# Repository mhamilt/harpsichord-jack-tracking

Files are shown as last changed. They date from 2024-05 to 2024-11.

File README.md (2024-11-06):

# Harpsichord Jack Tracking

This repository collects together all materials (CAD Drawings, diagrams, firmware source code) related to Harpsichord Jack Tracking Project at the NEMUS project.

|                              |
| :---------------------------------------------------------: |
| Side View of the model harpsichord used during development. |

- [Harpsichord Jack Tracking](#harpsichord-jack-tracking)
  - [Measurements](#measurements)
    - [Model Keyboard](#model-keyboard)
    - [Jack Pitch](#jack-pitch)
    - [Full Scale Keyboard](#full-scale-keyboard)
    - [Jack Pitch](#jack-pitch-1)
    - [Jack Travel](#jack-travel)
    - [PCB](#pcb)
      - [7 Sensor Face Board](#7-sensor-face-board)
    - [Gradient Tag](#gradient-tag)
    - [Diagram](#diagram)
  - [QRE1113 Notes](#qre1113-notes)
    - [Spacing](#spacing)
    - [Functionality](#functionality)
    - [Data sheets](#data-sheets)
    - [Multiplexing](#multiplexing)
      - [1. Using 2 Micro controllers](#1-using-2-micro-controllers)
  - [MIDI Specifications](#midi-specifications)
    - [Jack Differentiation](#jack-differentiation)
    - [Aftertouch](#aftertouch)

## Measurements

### Model Keyboard

###  Jack Pitch

| Jack | Centre distance from backboard (mm) |
| ---- | --- |
| 1 | `10.25` |
| 2 | `25.1` |
| 3 | `38.5` |

Gives a rough jack pitch of `14.4875 mm` with an offset of `10.25 mm`.

Pitch of the back row of jacks was determined by measuring from the open edge of the model to the front edge of the jack. Each jack had its width measured providing the values in the table below.

| Jack | Front edge dist (mm) | Width (mm) | Centre dist (mm) |
| ---- | --- | --- | --- |
| 4 | `59.85` | `4.25` | `61.975` |
| 5 | `45.25` | `4.30` | `47.400` |
| 6 | `31.20` | `4.60` | `33.500` |

Give a rough pitch of `14.2375 mm` with an offset of  `33.5 mm` from the front edge

### Full Scale Keyboard 

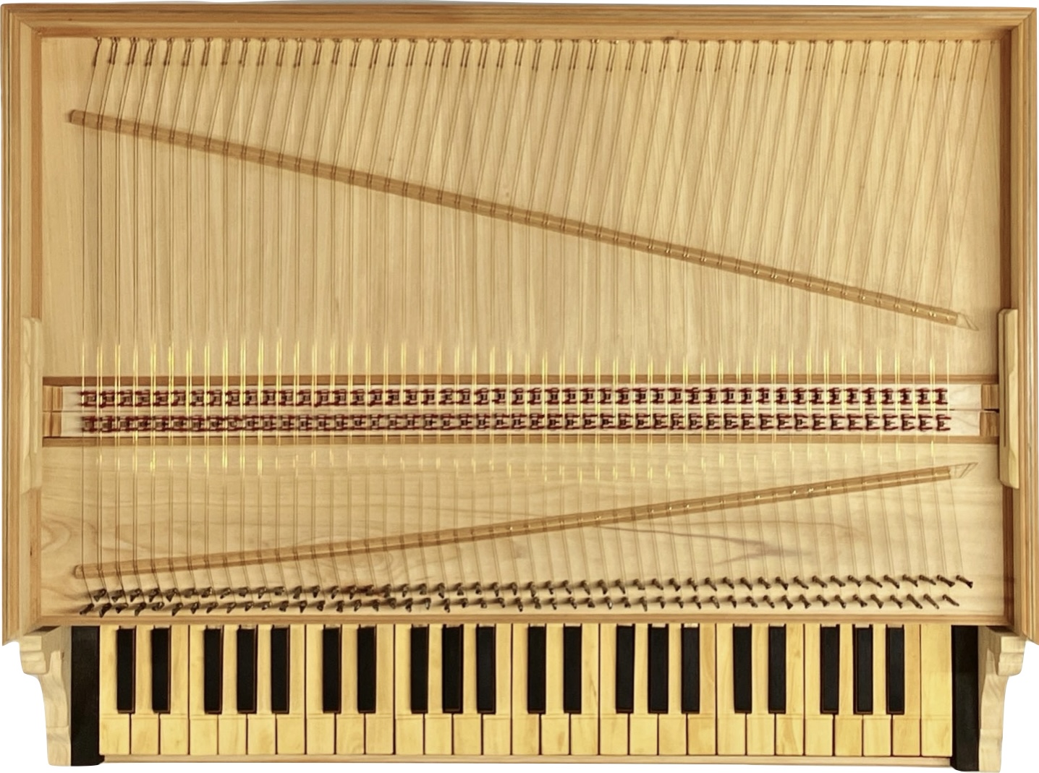
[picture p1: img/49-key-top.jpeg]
|        |
| :-----------------------------: |
| Top view of the 49-key keyboard |ll

The full scale version of the interface has 49 keys and 2 jack rows. The jacks are generally around `4.65 mm`.

###  Jack Pitch

There is not much variation in the pitch of the jacks. On average the centre-to-centre is `14.02 mm`. Likely error between jacks would compound across the full length. This should be compensated for by the separate pcbs which have groups of 7 sensors.

Space between the jacks is `9.75 mm`, meaning central pcbs will have to have less than half this distance (`4.875mm`) in order to slot together.

###  Jack Travel

The jacks have a height of `91.65mm`. Front jacks have a travel of about `8.5mm` and back jacks `9.0mm` between key release and full key press.

### PCB

With a pitch of `14.02 mm` a theoretical limit to the width of a 7-sensor PCB would be `98.2 mm`, but with margin required from traces this is not possible. The upper limit is `112.22 mm` but with variation during fabrication it is unwise to push the tolerance to the nearest `1/10 mm`. A `1.5 mm` tolerance brings the limit to about `99.7 mm` to `110.7 mm`

#### 7 Sensor Face Board

Face boards mount the QRE1113s perpendicular to the board so that there is no need to bend the through hole mounting legs during assembly.

There are a couple of designs, at at present what is most important is the hole mounts at (`18.00mm`, `10.00mm`) and (`18.00mm`, `81.40mm`)

### Gradient Tag

The QRE1113 reflects from a tag with a gradient printed.

The should be `40 mm` in length to avoid potential catching on the jack hole. The active area of the gradient need only be the length of the [jack travel](#jack-travel)

### Diagram

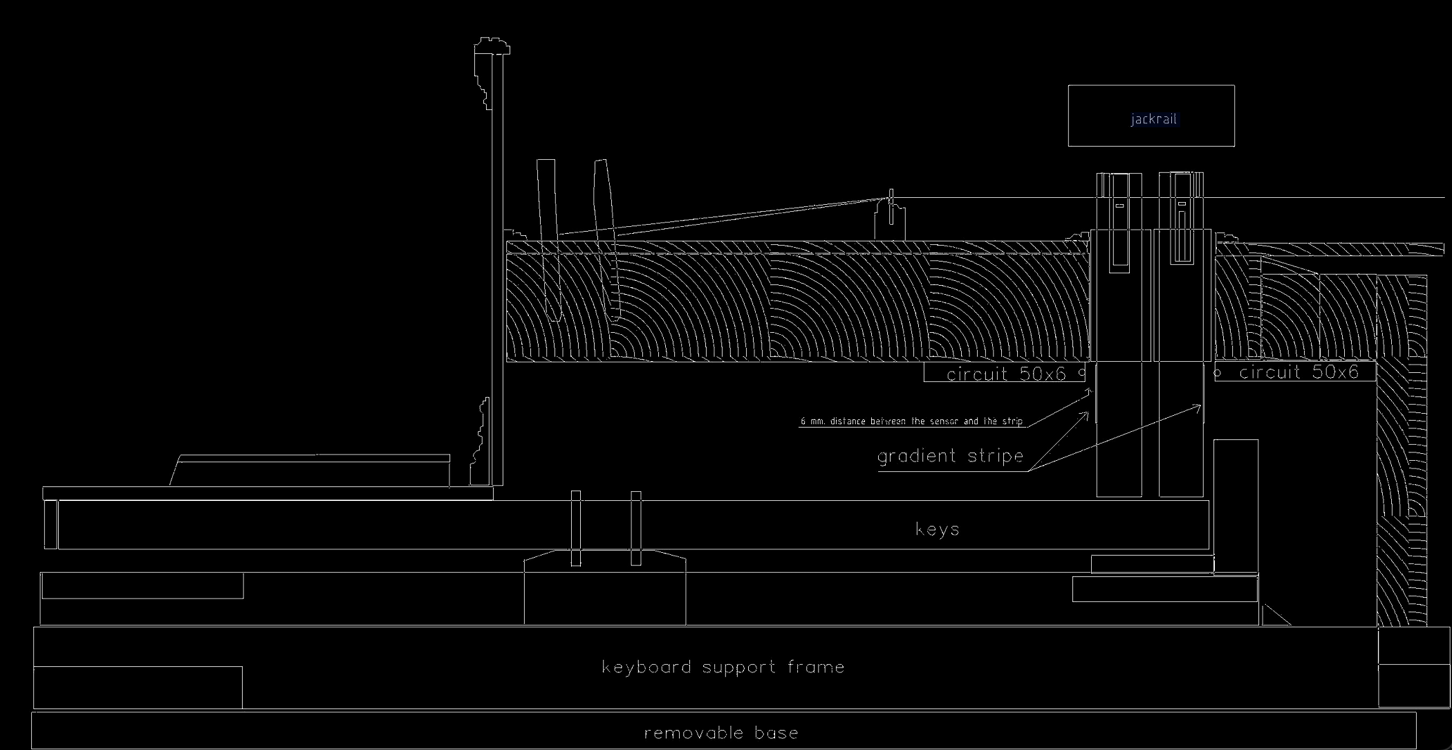
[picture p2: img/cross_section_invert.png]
|                 |
| :-----------------------------------------------: |
| Cross-section of full sized harpsichord interface |

## QRE1113 Notes

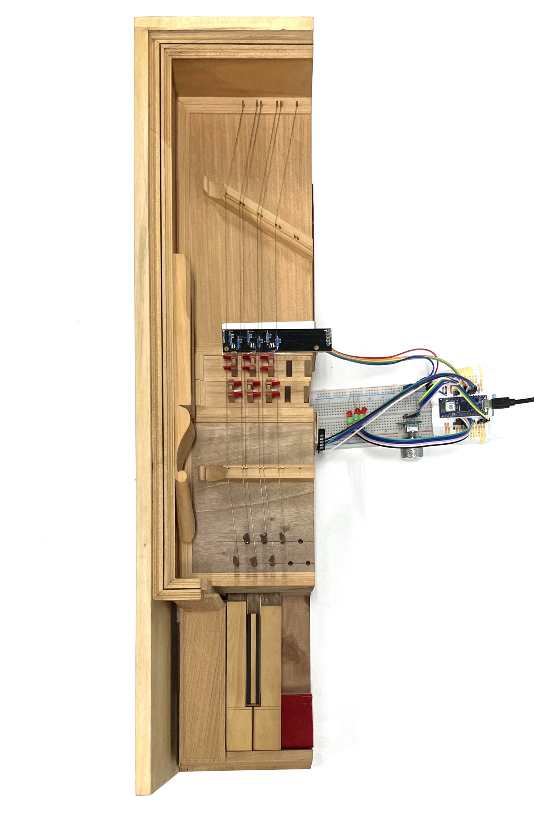
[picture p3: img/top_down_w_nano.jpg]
|              |
| :---------------------------------------------------------: |
| Model keyboard and QRE1113s attached to Arduino Nano 33 IoT |

Displacement of the jacks is measure using QRE1113 IR LED / Transistor pair. The section covers some general observations and helpful information about these sensors.

### Spacing

Distance between pins is `1.8mm` meaning the space from the centre is `0.9mm`. CAD placement should offset by `0.9mm` to compensate.

| | |
| --- | --- |
| short leg pitch | `1.80mm` |
| long leg pitch  | `3.80mm` |

### Functionality

QRE1113s are used with alongside adhesive strips with a black and white gradient printed on it, which are attached to each jack. 

The optimal distance between the strip and the sensor is around 6mm with a voltage reference of [`1.65V` provided by Arduino SAMD boards](https://www.arduino.cc/reference/en/language/functions/analog-io/analogreference/)

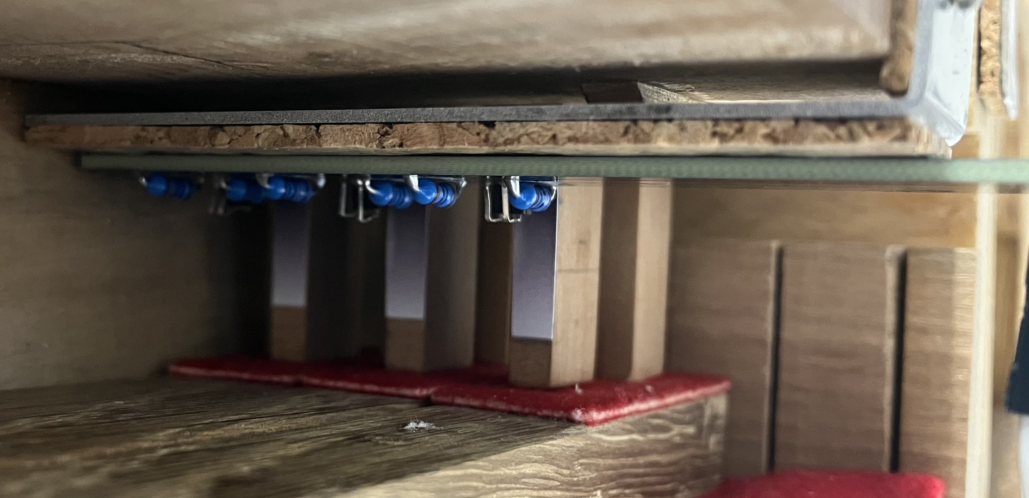
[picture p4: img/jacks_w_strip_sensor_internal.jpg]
|  |
| :-----------------------------------------: |
|     Jacks with gradient strip attached      |

### Data sheets

- [QRE1113 Datasheet](https://www.mouser.in/datasheet/2/308/QRE1113-1121523.pdf)

|  |  |
| :---: | :---: |
| QRE1113 Dimension. Not that pin 1 should always have a chamfer on the corner to help identify it. | QRE1113 Pinout |

### Multiplexing

- 14 Boards
- 7 sensors each
- 7 analog channels
- 8 channel multiplexer

- BLE Nano
  - 8 ADC channels A0 - A7
  - For 8 ADC channels an 8-channel multiplexer will allow for 8 boards to address 8 sensors.

Solutions:

1. Use 2 micro controllers, one for front, one for back
  - each a separate MIDI device
2. cascade front and back
  1. two groups of transistors
      - 16 transistors
        - 2 sets of 7 for signals
        - 2 extra for interfacing with the others
      - 2 extra digital pins used
  2. another bank of multiplexers
      - 7 multiplexers for groups of seven boards
      - 3 more digital pins for control 

#### 1. Using 2 Micro controllers

- Each sensor board needs 8 pins
  
  1. GND 
  2. VCC/VDD 5V
  3. VDD 3V
  4. Mux Address A
  5. Mux Address B
  6. Mux Address C
  7. LED Data
  8.  Signal 1
  9.  Signal 2
  10. Signal 3
  11. Signal 4
  12. Signal 5
  13. Signal 6
  14. Signal 7

## MIDI Specifications

Below are additional MIDI specifications retrieve the most information from the controller. 

Currently this is being written and subject to change

### Jack Differentiation

There is one channel per key as per [Standard MPE specifications](https://midi.org/mpe-midi-polyphonic-expression#:~:text=The%20MPE%20specification%20defines%20a,products%2C%20using%20MIDI%201.0%20messages.).

There are two note ons with associated velocities and note offs

A `note on` message `channel`, `pitch value`, `velocity`.

Velocity demarcates wether the note on message is related to the first jack or the second jack.

Given the signal obtained from the jack tracking does not provide the resolution in velocity to utilize the full 7 bit set of velocity values.

The First jack uses the velocity values from `0` to `63` and the second jack from `64` to `127`.

Note off messages use the same specification.

Therefore the physical model can relate the note off message to it's respective note on message.

example:

| | Jack1 | Jack2  |
| --- | ----- | --- |
| `channel`  | 1 | 1 |
| `pitch` | 56 | 56 |
| `velocity` | 0-63  | 64-127 |

**NOTE:** There is a secondary use case where the controller is used with a digital instrument that expects a standard MPE signal. In that case there _may_ be problem. However, it is not guaranteed to not work. Behavior in this case is undefined.

The same is true of the plug-in, which will be written to expect the above format of note messages.
As a result, the plug-in will need two modes of operation. A standard MPE for using with a standard MPE keyboard requiring a single note on/note off per key. The second mode designed specifically for the harpsichord keyboard interface. This gives control of the excitation of both of the strings.

### Aftertouch

Channel Pressure (MIDI Status event nybble `0xD`) is sent as one stream, taken from the front jack tracking signal.

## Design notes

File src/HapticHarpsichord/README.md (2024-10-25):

# Haptic Harpsichord Firmware

This documentation contain information for developing and deploying the firmware for the Haptic Harpsichord MIDI Controller

## Wiring

Pin layout adheres to the Arduino nano form factor
  
| Connection | Pin |
| --- | ----- |
| EEPROM SPI CLK  | D13 |
| EEPROM VCC | 3.3v  |
| AREF POT Switch | AREF  |
| PCB 0 QRE1113 | A0 |
| PCB 1 QRE1113 | A1 |
| PCB 2 QRE1113 | A2 |
| PCB 3 QRE1113 | A3 |
| PCB 4 QRE1113 | A4 |
| PCB 5 QRE1113 | A6 |
| PCB 6 QRE1113 | A7 |
| NC | 5v |
| NC | RESET |
| GND | GND |
| PSU `+` | VIN |

| Connection | Pin |
| --- | --- |
| Rotary CLK | D12 |
| Rotary DATA | D11 |
| Rotary Switch | D10 |
| LED Data | D9 |
| Mux C | D8 |
| Mux B | D7 |
| Mux A | D6 |
| Mux Interrupt | D5 |
| EEPROM SPI MISO | D4 |
| EEPROM SPI MOSI | D3 |
| EEPROM SPI CS | D2 |
| NC | RX / D1 |
| NC | TX / D0 |

## MIDI

## Power

The Arduino and the circuit are to be powered by 5V 5A PSU.

## Troubleshoooting

### Sensor Data Noise

If the sensors seem to return random noise and do not respond to an IR LED it is possible the interrupt for the multiplexers is not connected or is at a positive voltage. Ground the INT pin of the multiplexer.

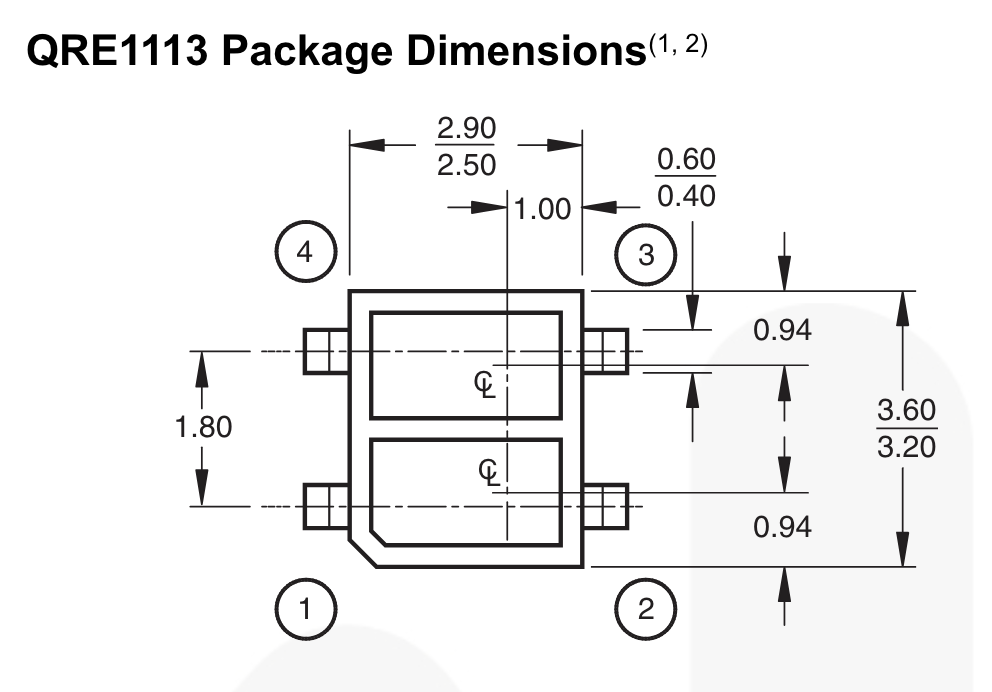
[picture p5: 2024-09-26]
img/qre1113-dims.png

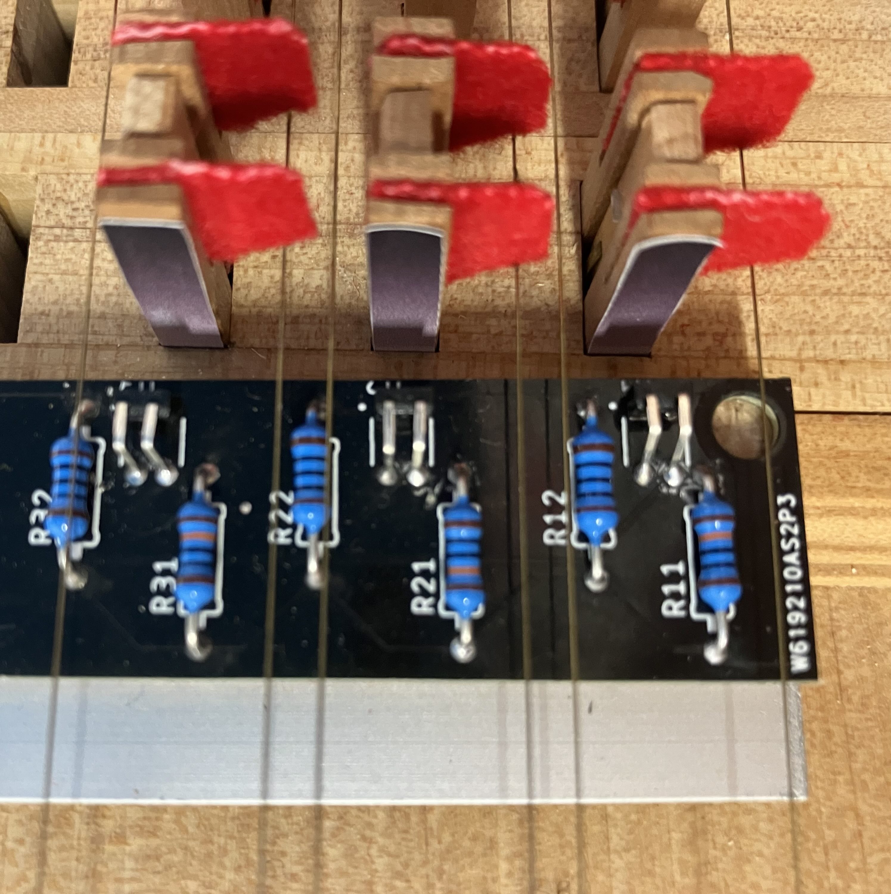
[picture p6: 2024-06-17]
img/jacks_w_strip_sensor.jpg

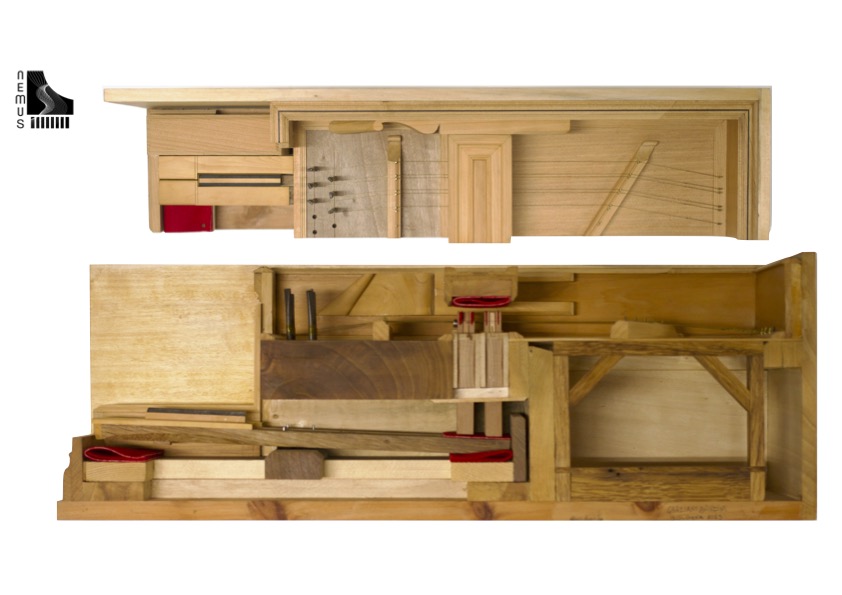
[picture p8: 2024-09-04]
img/haptic-harpsichord.jpg

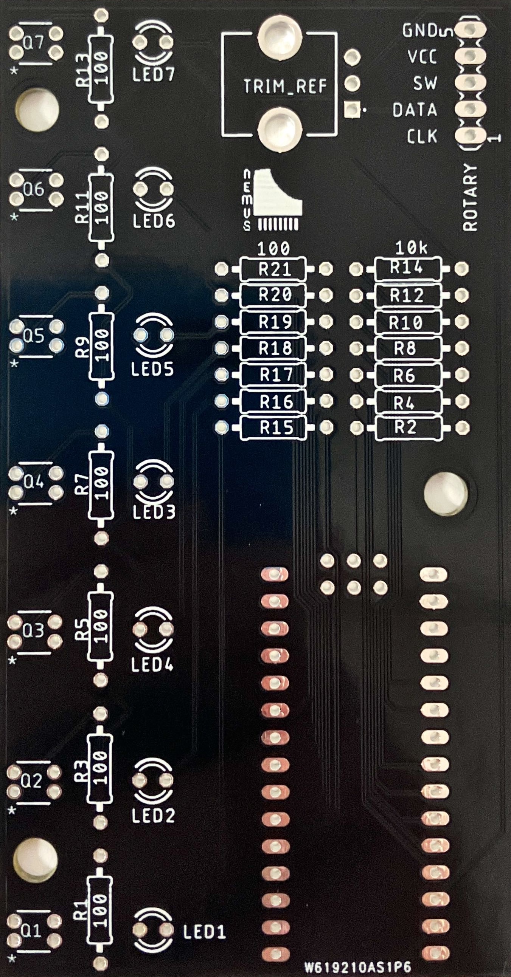
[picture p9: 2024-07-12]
img/7-jack-pcb.jpeg

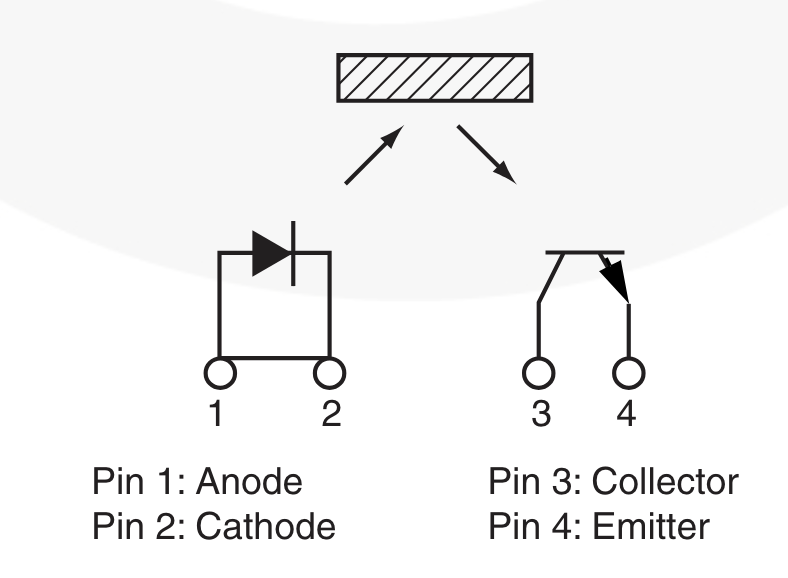
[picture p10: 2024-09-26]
img/qre1113-pins.png

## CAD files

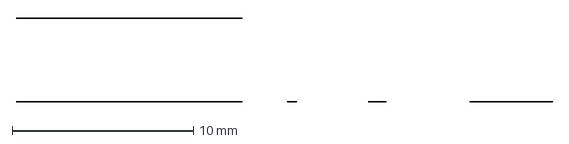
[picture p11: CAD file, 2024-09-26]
img/3-Key-Jack v18.dxf
29.6 x 4.60 mm

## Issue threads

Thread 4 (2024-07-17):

Tags sticking on full size model

mhamilt, 2024-07-17:
he gradient age length for the full size model (`20 mm` x `5 mm`) is too short and as a result the upper lip of the tag is getting caught during playing.

Probably easiest solved by extending the length of the tag. `40 mm` should do it

mhamilt, 2024-12-03:
Solved by cutting tag to full length of jack

Closed 2024-12-03.

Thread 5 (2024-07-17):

Redesign tag for full size model

mhamilt, 2024-07-17:
The distance of travel under the sensor is only around 9mm. The gradient could maybe do with a redesign to accommodate this, bearing in mind #4

Closed 2024-12-03.

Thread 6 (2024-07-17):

3D model for PCB supports

mhamilt, 2024-07-17:
A bracket is needed for adjusting PCB distance and making the installation more robust.

A fork bracket of some sort would allow for mounting a pub with sensors and pcb that are inline

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

28 units will be needed.

mhamilt, 2024-12-03:
Done

Models can be found in https://github.com/mhamilt/haptic-harpsichord-cad under the `stl/` directory for each PCB design.

3D printing and design in CAD is by far the best option so far.

Closed 2024-12-03.

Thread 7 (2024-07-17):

QRE1113 pcb redesign

mhamilt, 2024-07-17:
The QRE1113s used are those for through-hole mounting. At the moment, the design requires that the legs be bent but this is too costly in time and two risky as the legs easily break.

A new design is required where the QRE1113s can just be dropped in. This would mean that the PCB would sit at a 90º angle to the bracket #6. An additional L bracket would be needed

mhamilt, 2024-12-03:
Designs in https://github.com/mhamilt/haptic-harpsichord-cad

Closed 2024-12-03.

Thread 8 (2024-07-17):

QRE1113 Range Drop

mhamilt, 2024-07-17:
## The problem

There seems to be a drop in the full range of values from each sensor.

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

It roughly correlates with the distance each sensor is from the 3.3v source pin.

The closer each output is to `0` the lower the voltage.

I don't think this is a current problem. The board is use is an Arduino Nano 33 BLE, which has a max current for the 3.3v as `950 mA` [according to the datasheet](https://docs.arduino.cc/resources/datasheets/ABX00030-datasheet.pdf#page=6).

From the [QRE1113 datasheet](https://www.mouser.in/datasheet/2/308/QRE1113-1121523.pdf#page=4), each sensor is maximally rated to `70 mA`, `20 mA` for the sensor transistor collector and `50 mA` for the emitter. a `100 ohm` resistor has been used in front of the VCC pin for each QRE1113. This means max `33 mA` should be going to each QRE1113 unit, around `230 mA` total for 7 sensors.

The problem shouldn't be under current, but there is possibly a flaw in the approach to the layout of the trace on the PCB

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

| 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 |
| -------------------------------------------------------------- |
| Note the 3.3V line from the penultimate pin on the bottom left from each sensor taps into |

It may also be just variation within the sensors. More testing required.

## Solutions

Should be ablate adjust in software, the ranges available are still more than enough for MIDI purposes.

It may be worth while adding in a trim pot for each sensor to help adjust, but applying that to 98 sensor seems quite drastic.

This may also be addressed by simply powering the sensors as and when they are needed.

mhamilt, 2024-12-03:
Most likely this was done to sensor tag placement. After implementing on the full model, all sensors _could_ be made to give  similar reading so long as the gradient of the sensor surface was placed.

Variations in

- jack height
- leather thickness
- tag placement
- key thickness
- key displacement

mean that there will always be some variation, but data should be useable.

Closed 2024-12-03.

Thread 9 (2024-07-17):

Power Electronics

mhamilt, 2024-07-17:
At some point this device is actually going to need to be powered somehow.

If the current design is expanded to all 98 jacks, the power draw would be around 4A.

Need to find a suitable voltage regulator / converter for both the microcontroller and all sensors

mhamilt, 2024-12-03:
After testing, 49 sensors draw around 1 Amp at 5V.

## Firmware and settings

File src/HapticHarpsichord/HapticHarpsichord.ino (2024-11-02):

/*
  Haptic Harposchord

  This is the full firmware for the haptic harpsochord using the arduino IDE development platform

  At time of writing the microcontroller for the project is not fixed. As such there may be macros to help make the correct changes to firmware behaviour.

  | Connection      | Pin   |
  | --------------- | ----- |
  | NC              | D13   |
  | EEPROM VCC      | 3.3v  |
  | AREF POT Switch | AREF  |
  | PCB 0 QRE1113   | A0    |
  | PCB 1 QRE1113   | A1    |
  | PCB 2 QRE1113   | A2    |
  | PCB 3 QRE1113   | A3    |
  | PCB 4 QRE1113   | A4    |
  | PCB 5 QRE1113   | A6    |
  | PCB 6 QRE1113   | A7    |
  | NC              | 5v    |
  | NC              | RESET |
  | GND             | GND   |
  | PSU `+`         | VIN   |

  | Connection      | Pin     |
  | --------------- | ------- |
  | Rotary CLK      | D12     |
  | Rotary DATA     | D11     |
  | Rotary Switch   | D10     |
  | LED Data        | D9      |
  | Mux C           | D8      |
  | Mux B           | D7      |
  | Mux A           | D6      |
  | EEPROM SPI CLK  | D5      |
  | EEPROM SPI MISO | D4      |
  | EEPROM SPI MOSI | D3      |
  | EEPROM SPI CS   | D2      |
  | NC              | RX / D1 |
  | NC              | TX / D0 |


 */
//-----------------------------------------------------------------------------
// Board specific libraries
#ifdef ARDUINO_ARDUINO_NANO33BLE
#include <PluggableUSBMIDI.h>
#elif ESP32
#include <Arduino.h>
#include <Adafruit_TinyUSB.h>  // verision 3.1.3
#include <MIDI.h>
#elif ARDUINO_ARCH_STM32
#endif
//-----------------------------------------------------------------------------
// Board Agnostics Libraries
#include <Rotary.h>
#include <Button2.h>
#include <Adafruit_NeoPixel.h>
#include <Adafruit_FRAM_SPI.h>
#include <SPI.h>
//-----------------------------------------------------------------------------
// Local Headers
#include "error_codes.h"
//-----------------------------------------------------------------------------
#define ALWAYS_DEBUG true
//-----------------------------------------------------------------------------
// Enums
enum JackState {
  PLUCKED,
  PLUCK,
  PRESSING,
  RELEASING,
  RELEASED,
  UNKNOWN_KEY_STATE
};
//-----------------------------------------------------------------------------
#define numSensors 49
#define numMuxChannels 7
#define numPcbs 7

#if (numMuxChannels * numPcbs != numSensors)
#error "Check product of mux channels and number of PCBs is equal to total number of sensors"
#endif
//-----------------------------------------------------------------------------
constexpr byte key2index(byte k);
byte index2note(byte index, byte transpose = 0);
void rotate(Rotary& r);
//-----------------------------------------------------------------------------
// Config Variables
const unsigned long midiBaudRate = 115200;  // 31250;
bool executeDebugMode = false;
//-----------------------------------------------------------------------------
// Operation Mode Variables
bool isKeySelectMode = true;
uint8_t curKeyIndex = key2index(25);
//-----------------------------------------------------------------------------
// Multiplexer Variables
const size_t muxPinA = 6;
const size_t muxPinB = 7;
const size_t muxPinC = 8;
// const size_t muxPinD = 9;
//-----------------------------------------------------------------------------
// Sensor variables
uint16_t sensorReadingsA[numSensors];
uint16_t sensorReadingsB[numSensors];
// uint16_t lastSensorReading[numSensors];
uint16_t* tempPointer;
uint16_t sensorAvgMaxima[numSensors];
uint16_t sensorAvgMinima[numSensors];
uint16_t pluckThresholds[numSensors];
uint16_t releaseThresholds[numSensors];
uint32_t readCount = 0;
uint64_t lastRead = 0;
constexpr byte avgSize = 4;
uint16_t sensorWindowReadings[numSensors][avgSize];
byte windex = 0;
uint16_t* prevSensorReadings = sensorReadingsB;
uint16_t* currSensorReadings = sensorReadingsA;
//-----------------------------------------------------------------------------
// Jack States
JackState jackStatesA[numSensors];
JackState jackStatesB[numSensors];
JackState* jackStates = jackStatesA;
JackState* prevStates = jackStatesB;
JackState* tempStatePointer;
//-----------------------------------------------------------------------------
// LED Variables
const size_t ledPin = 9;
Adafruit_NeoPixel leds(numSensors, ledPin, NEO_GRB + NEO_KHZ800);
unsigned long now = 0;
static int step = 0;

//-----------------------------------------------------------------------------
// Rotary Variables
const byte ROTARY_PINC = 12;
const byte ROTARY_PINA = 10;
const byte ROTARY_PINB = 11;
const byte CLICKS_PER_STEP = 4;
const byte MIN_POS = 0;
const uint16_t MAX_POS = numSensors - 1;
const byte START_POS = 0;
const byte INCREMENT = 1;
Rotary rotary = Rotary(ROTARY_PINA, ROTARY_PINB, CLICKS_PER_STEP, MIN_POS, MAX_POS, START_POS, INCREMENT);
Button2 button = Button2(ROTARY_PINC);
//-----------------------------------------------------------------------------
// EEPROM Variables
const uint8_t FRAM_CS = 2;
const uint8_t FRAM_MOSI = 3;
const uint8_t FRAM_MISO = 4;
const uint8_t FRAM_SCK = 5;
Adafruit_FRAM_SPI fram = Adafruit_FRAM_SPI(FRAM_SCK, FRAM_MISO, FRAM_MOSI, FRAM_CS);
const uint8_t addrSizeInBytes = 2;  // Default to address size of two bytes
const uint16_t tagAddress = 0;
const uint8_t thresholdTag[4] = { 'D', 'A', 'T', 'A' };
// const uint8_t maxTag[4] = { 'M', 'A', 'X', 'I' };
// const uint8_t minTag[4] = { 'M', 'I', 'N', 'I' };
const uint16_t pluckValAddress = tagAddress + 4;
//-----------------------------------------------------------------------------
// MIDI Variables
USBMIDI MidiUSB;

void setup() {
  Serial.begin(midiBaudRate);
  // Save some power
  digitalWrite(PIN_ENABLE_I2C_PULLUP, LOW);
  digitalWrite(PIN_ENABLE_SENSORS_3V3, LOW);
  // digitalWrite(LED_PWR, LOW);
  /// setup mux
  pinMode(muxPinA, OUTPUT);
  pinMode(muxPinB, OUTPUT);
  pinMode(muxPinC, OUTPUT);

  /// init LEDs
  pinMode(LEDR, OUTPUT);
  pinMode(LEDG, OUTPUT);
  pinMode(LEDB, OUTPUT);

  digitalWrite(LEDR, HIGH);
  digitalWrite(LEDG, HIGH);
  digitalWrite(LEDB, HIGH);

  for (int i = 0; i < numSensors; i++) {
    sensorAvgMinima[i] = 1024;
    pluckThresholds[i] = 500;
  }

  leds.begin();
  leds.clear();
  
  /// setup EEPROM
  if (!fram.begin())
    halt(FRAM_NOT_FOUND);

  readPluckFromEEPROM();

  // calibrarte sensors
  calibrate();

  if (button.isPressed() or ALWAYS_DEBUG) {
    debugLoop();
  }
}

void loop() {

  // readSensors();
  // rotary.loop();
  // button.loop();

  // for (int i = 0; i < numSensors; i++) {
  //   if (currSensorReadings[i] < pluckThresholds[i] and prevSensorReadings[i] > pluckThresholds[i]) {
  //     noteOff(0, index2note(i), 100);
  //   } else if (currSensorReadings[i] > pluckThresholds[i] and prevSensorReadings[i] < pluckThresholds[i]) {
  //     noteOn(0, index2note(i), 100);
  //   }
  // }

  // readCount++;

  // if (readCount > 2048) {
  //   readCount = 0;
  //   Serial.println(millis() - lastRead);
  //   lastRead = millis();
  // }

    if (millis() - now > 16) {
      // rainbow(step++);
      breath(step++);
      now = millis();
    }
    // rotary.loop();
  
}

void calibrate() {
  static const int numReading = 8;

  for (int i = 0; i < numSensors; i++) {
    unsigned long runningTotal = 0;

    for (int k = 0; k < numReading; k++) {
      runningTotal += readSensor(i);
    }
    sensorAvgMaxima[i] = runningTotal /= numReading;
  }
}

constexpr byte index2key(byte i) {
  return (numSensors - i);
}

constexpr byte key2index(byte k) {
  if (k > numSensors)
    k = numSensors;
  else if (k < 1)
    k = 1;
  return (numSensors - k);
}

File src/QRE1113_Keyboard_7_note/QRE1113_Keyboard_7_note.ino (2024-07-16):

/*
  QRE1113  6-Note Keyboard
  
  Firmware for 3-key, 6-jack Harpsochord model


  Wiring:
  
    |   Connection   | Pin |
    | -------------- | --- |
    | Jack 0 QRE1113 | A0  |
    | Jack 1 QRE1113 | A1  |
    | Jack 2 QRE1113 | A2  |
    | Jack 3 QRE1113 | A3  |
    | Jack 4 QRE1113 | A4  |
    | Jack 5 QRE1113 | A6  |
    | Jack 6 QRE1113 | A7  |
    | Jack 0 LED     | D9  |
    | Jack 1 LED     | D8  |
    | Jack 2 LED     | D7  |
    | Jack 3 LED     | D6  |
    | Jack 4 LED     | D5  |
    | Jack 5 LED     | D4  |
    | Jack 6 LED     | D3  |
    | Rotary CLK     | D12 |
    | Rotary DATA    | D11 |
    | Rotary Switch  | D10 |

  Jack Layout:

    ┌─┐┌─┐┌─┐
    ┤3│┤4│┤5│
    └─┘└─┘└─┘
    ┌─┐┌─┐┌─┐
    │0├│1├│2├
    └─┘└─┘└─┘

    ┌──┬─┬──┐
    │  │ │  │
    │  │ │  │
    │  │ │  │
    │  └┬┘  │
    │   │   │
    │   │   │
    └───┴───┘
*/
//-----------------------------------------------------------------------------
#include <MIDIUSB.h>
#include <Rotary.h>
#include <Button2.h>
#include <FlashStorage_SAMD.h>
//-----------------------------------------------------------------------------

enum JackState {
  PLUCKED,
  PLUCK,
  PRESSING,
  RELEASING,
  RELEASED,
  UNKNOWN_KEY_STATE
};

//-----------------------------------------------------------------------------
// Sensor variables
const byte numSensors = 6;
unsigned long sensorAverages[numSensors];
unsigned long sensorHomeValues[numSensors];
const pin_size_t sensorPins[numSensors] = { A0, A1, A2, A3, A6, A7 };
const byte ledPins[numSensors] = { 3, 5, 7, 2, 4, 6 };
const bool ledFeedback = true;
int sensorValues[numSensors] = { 0, 0, 0, 0, 0, 0 };
int prevValues[numSensors] = { 0, 0, 0, 0, 0, 0 };
byte noteMap[numSensors] = { 70, 71, 72, 70, 71, 72 };
byte pluckValues[numSensors] = { 65, 80, 180, 80, 77, 36 };
byte releaseValues[numSensors] = { 24, 24, 24, 24, 24, 24 };
JackState jackStates[numSensors] = { RELEASED, RELEASED, RELEASED, RELEASED, RELEASED, RELEASED };
JackState prevStates[numSensors] = { RELEASED, RELEASED, RELEASED, RELEASED, RELEASED, RELEASED };
//-----------------------------------------------------------------------------
// Rotary Variables
const byte BUTTON_PIN = 10;
const byte ROTARY_PIN1 = 11;
const byte ROTARY_PIN2 = 12;
const byte CLICKS_PER_STEP = 4;
const byte MIN_POS = 0;
const byte MAX_POS = numSensors - 1;
const byte START_POS = 0;
const byte INCREMENT = 1;
Rotary r = Rotary(ROTARY_PIN1, ROTARY_PIN2, CLICKS_PER_STEP, MIN_POS, MAX_POS, START_POS, INCREMENT);
Button2 b = Button2(BUTTON_PIN);
byte curKey = 0;
bool isKeySelectMode = true;
bool executeDebugMode = false;
//-----------------------------------------------------------------------------
// EEPROM Vars
const uint16_t tagAddress = 0;
const char tagName[4] = { 'D', 'A', 'T', 'A' };
const uint16_t pluckValAddress = tagAddress + 4;
//-----------------------------------------------------------------------------

void setup() {
  analogReference(AR_INTERNAL1V65);
  Serial.begin(9600);
  calibrate();
  readPluckFromEEPROM();
  for (auto pin : ledPins) {
    pinMode(pin, OUTPUT);
  }
  delay(200);  // give some padding to allow button to be pressed

  if (b.isPressed()) {

    setupDebugMode();

    while (executeDebugMode)
      debugModeLoop();

    exitDebug();
  }
}

void loop() {
  updateSensorReadings();
  updateJackStates();
  // printReadings();
  checkJackStates();
  printJackStates();
  delay(1);
}

//-----------------------------------------------------------------------------

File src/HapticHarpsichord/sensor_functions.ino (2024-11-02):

/// Read all sensors and put results in currSensorReadings
void readSensors() {

  for (int mux = 0; mux < numMuxChannels; mux++) {

    // switch mux channel
    digitalWrite(muxPinA, (mux >> 0) & 0x1);
    digitalWrite(muxPinB, (mux >> 1) & 0x1);
    digitalWrite(muxPinC, (mux >> 2) & 0x1);
    // digitalWrite(muxPinD, (mux >> 3) & 0x1);

    for (int adc = 0; adc < numPcbs; adc++) {

      int i = mux + (adc * numPcbs);

      sensorWindowReadings[i][windex] = analogRead(A0 + adc);

      uint16_t total = 0;

      for (int avg = 0; avg < avgSize; avg++) {
        total += sensorWindowReadings[i][avg];
      }

      currSensorReadings[i] = total / avgSize;
      // currSensorReadings[i] = analogRead(A0 + adc);
    }
  }
  
  windex++;
  if (windex >= avgSize) {
    windex = 0;
  }

  // pointer swap
  tempPointer = prevSensorReadings;
  prevSensorReadings = currSensorReadings;
  currSensorReadings = tempPointer;
}

//-----------------------------------------------------------------------------
/// Read a single sensor and return its raw value
unsigned int readSensor(byte index) {
  int adc = index / numPcbs;
  int mux = index - adc * numPcbs;

  digitalWrite(muxPinA, (mux >> 0) & 0x1);
  digitalWrite(muxPinB, (mux >> 1) & 0x1);
  digitalWrite(muxPinC, (mux >> 2) & 0x1);
  // digitalWrite(muxPinD, (mux >> 3) & 0x1);

  return analogRead(A0 + adc);
}


//-----------------------------------------------------------------------------
void calibrateSensors() {
  setThresholdsFromEEPROM();
  readSensors();
  setAverages();
}

//-----------------------------------------------------------------------------

void setThresholdsFromEEPROM() {
}

//-----------------------------------------------------------------------------

void setAverages() {
}

//-----------------------------------------------------------------------------

byte getOnVelocity(int j) {

  byte velocity;
  if (j < 3) {

    velocity = map(currSensorReadings[j] - prevSensorReadings[j], 1, 180, 1, 63);
    if (velocity < 1)
      velocity = 1;
    else if (velocity > 63)
      velocity = 63;

  } else {
    {
      velocity = map(currSensorReadings[j] - prevSensorReadings[j], 1, 180, 65, 127);
      if (velocity < 65)
        velocity = 65;
      else if (velocity > 127)
        velocity = 127;
    }
  }
}

//-----------------------------------------------------------------------------

byte getOffVelocity(int j) {
  byte velocity;
  if (j < 3) {

    velocity = map(currSensorReadings[j] - prevSensorReadings[j], 1, 180, 1, 63);
    if (velocity < 1)
      velocity = 1;
    else if (velocity > 63)
      velocity = 63;

  } else {
    {
      velocity = map(currSensorReadings[j] - prevSensorReadings[j], 1, 180, 65, 127);
      if (velocity < 65)
        velocity = 65;
      else if (velocity > 127)
        velocity = 127;
    }
  }
}

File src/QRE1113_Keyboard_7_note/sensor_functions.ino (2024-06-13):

//-----------------------------------------------------------------------------

void calibrate() {
  Serial.print("Calibrating.... ");

  for (int j = 0; j < 8; j++)
    for (int i = 0; i < numSensors; i++)
      sensorHomeValues[i] += analogRead(sensorPins[i]);

  for (int i = 0; i < numSensors; i++)
    sensorHomeValues[i] >>= 3;

  Serial.print("Done!");
}

//-----------------------------------------------------------------------------

void updateSensorReadings() {
  for (int i = 0; i < numSensors; i++) {
    prevValues[i] = sensorValues[i];
    sensorValues[i] = map(analogRead(sensorPins[i]), sensorHomeValues[i], 130, 0, 255);
    sensorValues[i] = (sensorValues[i] < 0) ? 0 : sensorValues[i];
  }
}

//-----------------------------------------------------------------------------

void updateJackStates() {

  for (int i = 0; i < numSensors; i++) {
    prevStates[i] = jackStates[i];
    if (prevValues[i] <= releaseValues[i]) {
      jackStates[i] = RELEASED;
    } else if (prevValues[i] < pluckValues[i] and sensorValues[i] > pluckValues[i]) {
      jackStates[i] = PLUCK;
    } else if (prevValues[i] > pluckValues[i] and sensorValues[i] > pluckValues[i]) {
      jackStates[i] = PLUCKED;
    }
  }
}

//-----------------------------------------------------------------------------

void checkJackStates() {
  bool anyTrigger = false;

  for (int i = 0; i < numSensors; i++) {
    if (jackStates[i] == PLUCK and prevStates[i] == RELEASED) {
      byte velocity = getVelocity(i);
      Serial.print("velocity: ");
      Serial.println(velocity);
      noteOn(0, noteMap[i], velocity);
      if (ledFeedback) {
        digitalWrite(ledPins[i], HIGH);
      }

    } else if (jackStates[i] == RELEASED and prevStates[i] != RELEASED) {
      byte velocity = prevValues[i] - sensorValues[i];
      noteOff(0, noteMap[i], velocity);
      if (ledFeedback) {
        digitalWrite(ledPins[i], LOW);
      }
    }
  }
}


byte getOnVelocity(int j) {
  byte velocity;
  if (j < 3) {

    velocity = map(sensorValues[j] - prevValues[j], 1, 180, 1, 63);
    if (velocity < 1)
      velocity = 1;
    else if (velocity > 63)
      velocity = 63;

  } else {
    {
      velocity = map(sensorValues[j] - prevValues[j], 1, 180, 65, 127);
      if (velocity < 65)
        velocity = 65;
      else if (velocity > 127)
        velocity = 127;
    }
  }
}

byte getOffVelocity(int j) {
  byte velocity;
  if (j < 3) {

    velocity = map(sensorValues[j] - prevValues[j], 1, 180, 1, 63);
    if (velocity < 1)
      velocity = 1;
    else if (velocity > 63)
      velocity = 63;

  } else {
    {
      velocity = map(sensorValues[j] - prevValues[j], 1, 180, 65, 127);
      if (velocity < 65)
        velocity = 65;
      else if (velocity > 127)
        velocity = 127;
    }
  }
}

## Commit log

2024-06-13 add wiring table
2024-06-17 add cad files
    [miniboard.brd, miniboard.sch]
2024-07-04 add cad data for 7-key protoboard
    [7-jack-sensor-board-nano.brd, 7-jack-sensor-board-nano.sch, 7-jack-sensor-board.sch]
2024-07-16 add src for 7 note pcb
2024-09-26 Create 3-Key-Jack v18.dxf
    [3-Key-Jack v18.dxf]
2024-11-01 add standard mode leds
2024-11-02 fix eeprom read bug
    [HapticHarpsichord.ino, debug_functions.ino, eeprom_functions.ino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]
2024-11-06 add printing again
2024-11-06 remove old cad
    [7-jack-sensor-board-nano.brd, 7-jack-sensor-board-nano.sch, 7-jack-sensor-board.sch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]
2024-11-06 add cad as submodule
